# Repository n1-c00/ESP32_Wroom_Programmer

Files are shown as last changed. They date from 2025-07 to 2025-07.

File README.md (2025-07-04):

# ESP32_Wroom_Programmer
This neat little board solves the issue always having a USB-UART Converter on your board when building a design with an ESP32. Some of you now may say "But this is just a simple USB-UART Converter I can get that on Aliexpress for a few €". But the thing that makes this sweet little board special, is that it has the auto-programming circuit from the ESP-Devboards. so by only exposing 5-6 Pins you can programm your custom PCB the same way you would do it on a Devkit (Plus it has USB-C but thats kinda the standard by now).

I hope you find it as usefull as me,
happy Building :)

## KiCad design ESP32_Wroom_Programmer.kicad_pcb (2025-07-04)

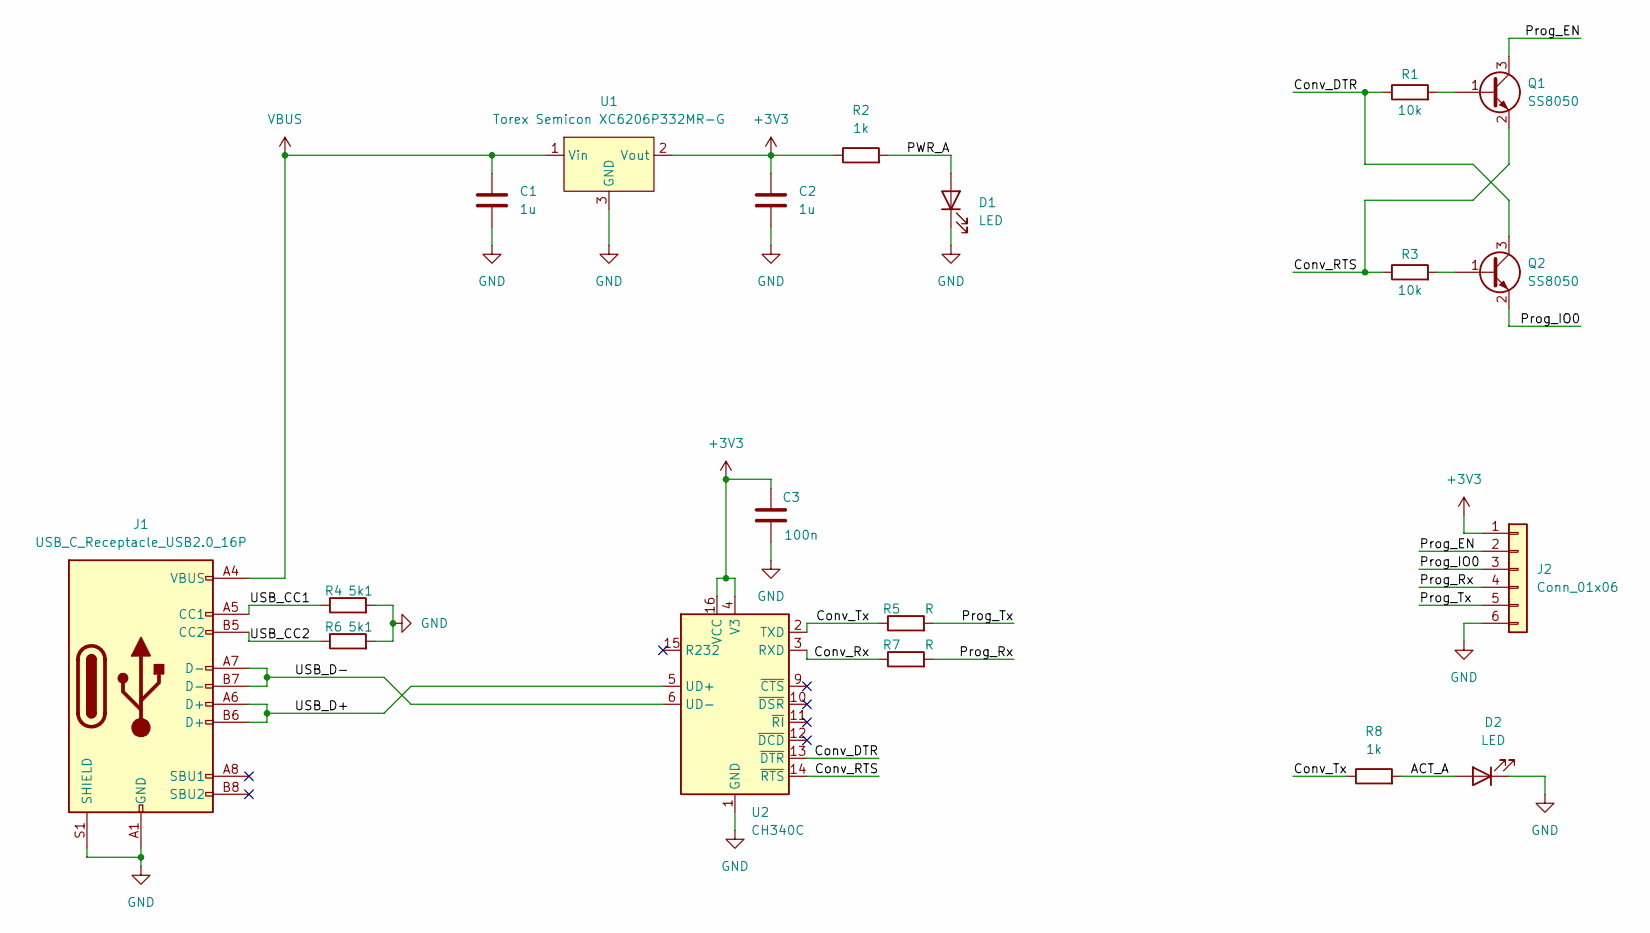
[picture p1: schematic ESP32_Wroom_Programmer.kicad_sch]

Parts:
C1, C2: 1u; C_0805_2012Metric
C3: 100n; C_0805_2012Metric
D1, D2: LED; LED_0805_2012Metric
J1: USB_C_Receptacle_USB2.0_16P; USB_C_Receptacle_GCT_USB4105-xx-A_16P_TopMnt_Horizontal
J2: Conn_01x06; PinHeader_1x06_P2.54mm_Horizontal
Q1, Q2: SS8050; SOT-23
R1, R3: 10k; R_0805_2012Metric
R2, R8: 1k; R_0805_2012Metric
R4, R6: 5k1; R_0603_1608Metric
R5, R7: R; R_0805_2012Metric
U1: Torex Semicon XC6206P332MR-G; SOT-23
U2: CH340C; SOIC-16_3.9x9.9mm_P1.27mm

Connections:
+3V3: C2.1, C3.1, J2.1, R2.1, U1.2 (Vout), U2.4 (V3), U2.16 (VCC)
/ACT_A: D2.2 (A), R8.2
/Conv_DTR: Q2.3 (C), R1.1, U2.13 (~DTR)
/Conv_RTS: Q1.2 (E), R3.1, U2.14 (~RTS)
/Conv_Rx: R7.1, U2.3 (RXD)
/Conv_Tx: R5.1, R8.1, U2.2 (TXD)
/PWR_A: D1.2 (A), R2.2
/Prog_EN: J2.2, Q1.3 (C)
/Prog_IO0: J2.3, Q2.2 (E)
/Prog_Rx: J2.4, R7.2
/Prog_Tx: J2.5, R5.2
/USB_CC1: J1.A5 (CC1), R4.1
/USB_CC2: J1.B5 (CC2), R6.1
/USB_D+: J1.A6 (D+), J1.B6 (D+), U2.5 (UD+)
/USB_D-: J1.A7 (D-), J1.B7 (D-), U2.6 (UD-)
GND: C1.2, C2.2, C3.2, D1.1 (K), D2.1 (K), J1.A1 (GND), J1.A12 (GND), J1.B1 (GND), J1.B12 (GND), J1.S1 (SHIELD), J2.6, R4.2, R6.2, U1.3 (GND), U2.1 (GND)
unnamed: Q1.1 (B), R1.2
unnamed: Q2.1 (B), R3.2
VBUS: C1.1, J1.A4 (VBUS), J1.A9 (VBUS), J1.B4 (VBUS), J1.B9 (VBUS), U1.1 (Vin)

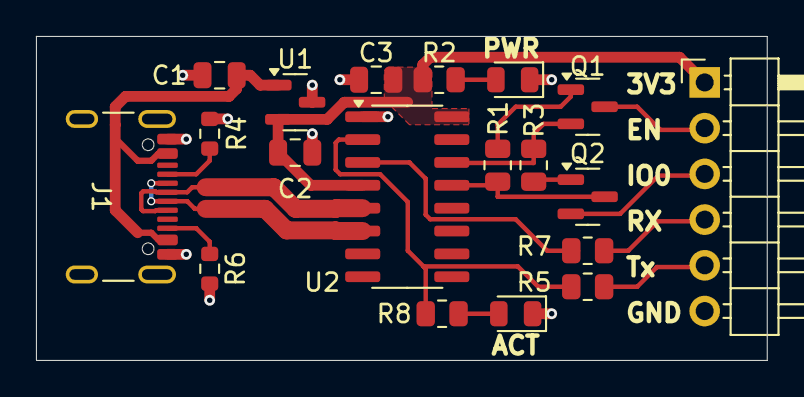
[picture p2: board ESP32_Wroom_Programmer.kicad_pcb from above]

Board: 2 copper layers, 40.6 x 18.0 mm, 19 parts (0 on the bottom side), 19 nets.

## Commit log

2025-07-03 First commit!
    [ESP32_Wroom_Programmer.kicad_pcb, ESP32_Wroom_Programmer.kicad_sch]
2025-07-04 first version of PCB finished!
    [ESP32_Wroom_Programmer.kicad_pcb, ESP32_Wroom_Programmer.kicad_sch]
2025-07-04 fixed missing +3V3 connections
    [ESP32_Wroom_Programmer.kicad_pcb]
2025-07-04 there were still some connections missing...
    [ESP32_Wroom_Programmer.kicad_pcb]
2025-07-04 added ground to USB-C Shield
    [ESP32_Wroom_Programmer.kicad_pcb, ESP32_Wroom_Programmer.kicad_sch]
